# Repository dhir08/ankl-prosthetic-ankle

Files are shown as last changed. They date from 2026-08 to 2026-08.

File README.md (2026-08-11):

# ANKL — 3-DOF Pediatric Prosthetic Ankle

A three-degree-of-freedom prosthetic ankle designed to emulate natural gait motion for a pediatric patient, developed across five 3D-printed design iterations with linear actuators, custom joints, and a purpose-built PCB.

**Stack:** SolidWorks (parts, assemblies, drawings) · FEA · 3D printing (PLA) · linear actuators · custom PCB · electrical schematics · kinematic modeling
**Context:** Biomedical Engineering Project, Texas A&M University — January 2026 – present
**Role:** Mechanical design, electrical schematic design, PCB layout, iteration testing

---

## The problem

Commercial prosthetic ankles are overwhelmingly designed for adult anatomy and adult gait. Pediatric patients get scaled-down adult hardware, which means the wrong mass distribution on a body that has less strength to carry it, and joint kinematics that don't match a growing gait pattern. Weight is the binding constraint: every gram at the distal end of the limb costs disproportionate metabolic energy during swing phase.

## What was built

A 3-DOF ankle assembly — dorsiflexion/plantarflexion, inversion/eversion, and internal/external rotation — driven by linear actuators through custom-designed joints, with a kinematic model used to size actuator stroke and mounting geometry against target range of motion before anything was printed.

### Headline result

**Device weight reduced 1.6×** by designing the electrical schematics and a custom PCB from scratch, replacing discrete wiring and off-the-shelf boards, then repackaging the mechanical envelope around the smaller board footprint. The electrical redesign didn't just save board mass — it collapsed the wiring harness volume, which let the housing shrink.

## Design process

Five full iterations, each following the same loop:

1. **Model** — full parts and assemblies in SolidWorks, driven by the kinematic model for joint placement and actuator stroke
2. **Print** — 3D-printed prototype build
3. **Validate** — fit and range-of-motion checks on the physical build
4. **Feed back** — dimensional changes carried into the CAD model before the next print cycle

That last step is the one that matters. Each print exposed tolerance stack-up and interference that the model didn't predict, and the CAD was corrected rather than the print being shimmed.

| Iteration | Focus |
| --- | --- |
| 1 | Baseline 3-DOF joint architecture, actuator mounting feasibility |
| 2 | Joint geometry refinement against measured range of motion |
| 3 | Tolerance and clearance correction from physical fit testing |
| 4 | Electrical integration — schematic design and custom PCB |
| 5 | Mechanical envelope repackaged around the new board; weight reduction realized |

## Electrical design

Schematics and custom PCB components were designed from scratch rather than assembled from breakout boards. The goals, in order: cut mass, cut wiring complexity, and shrink the volume the electronics demand from the mechanical housing.

## Repository contents

```
cad/
  parts/            SolidWorks part files (.SLDPRT)
  assemblies/       Full ankle assemblies (.SLDASM)
  drawings/         Technical drawings (.SLDDRW, PDF exports)
  step/             Neutral-format STEP exports
electrical/
  schematics/       Electrical schematics
  pcb/              PCB layout files and Gerbers
  bom.csv           Bill of materials
analysis/
  kinematics/       Kinematic model and range-of-motion calculations
  fea/              FEA setup and results
docs/
  iteration-log.md  Per-iteration changes, measurements, and rationale
  images/           Renders and build photos
```

## Next steps

- Gait-cycle load testing beyond static fit and range-of-motion validation
- Actuator control tuning against measured pediatric gait profiles
- Material study — evaluating printed PLA against carbon-filled alternatives for the load-bearing members

## A note on files

CAD binaries are versioned here for completeness, but Git handles them as opaque blobs — diffs aren't meaningful. STEP exports are included so the geometry is reviewable without a SolidWorks license.

## License

MIT — see [LICENSE](LICENSE).

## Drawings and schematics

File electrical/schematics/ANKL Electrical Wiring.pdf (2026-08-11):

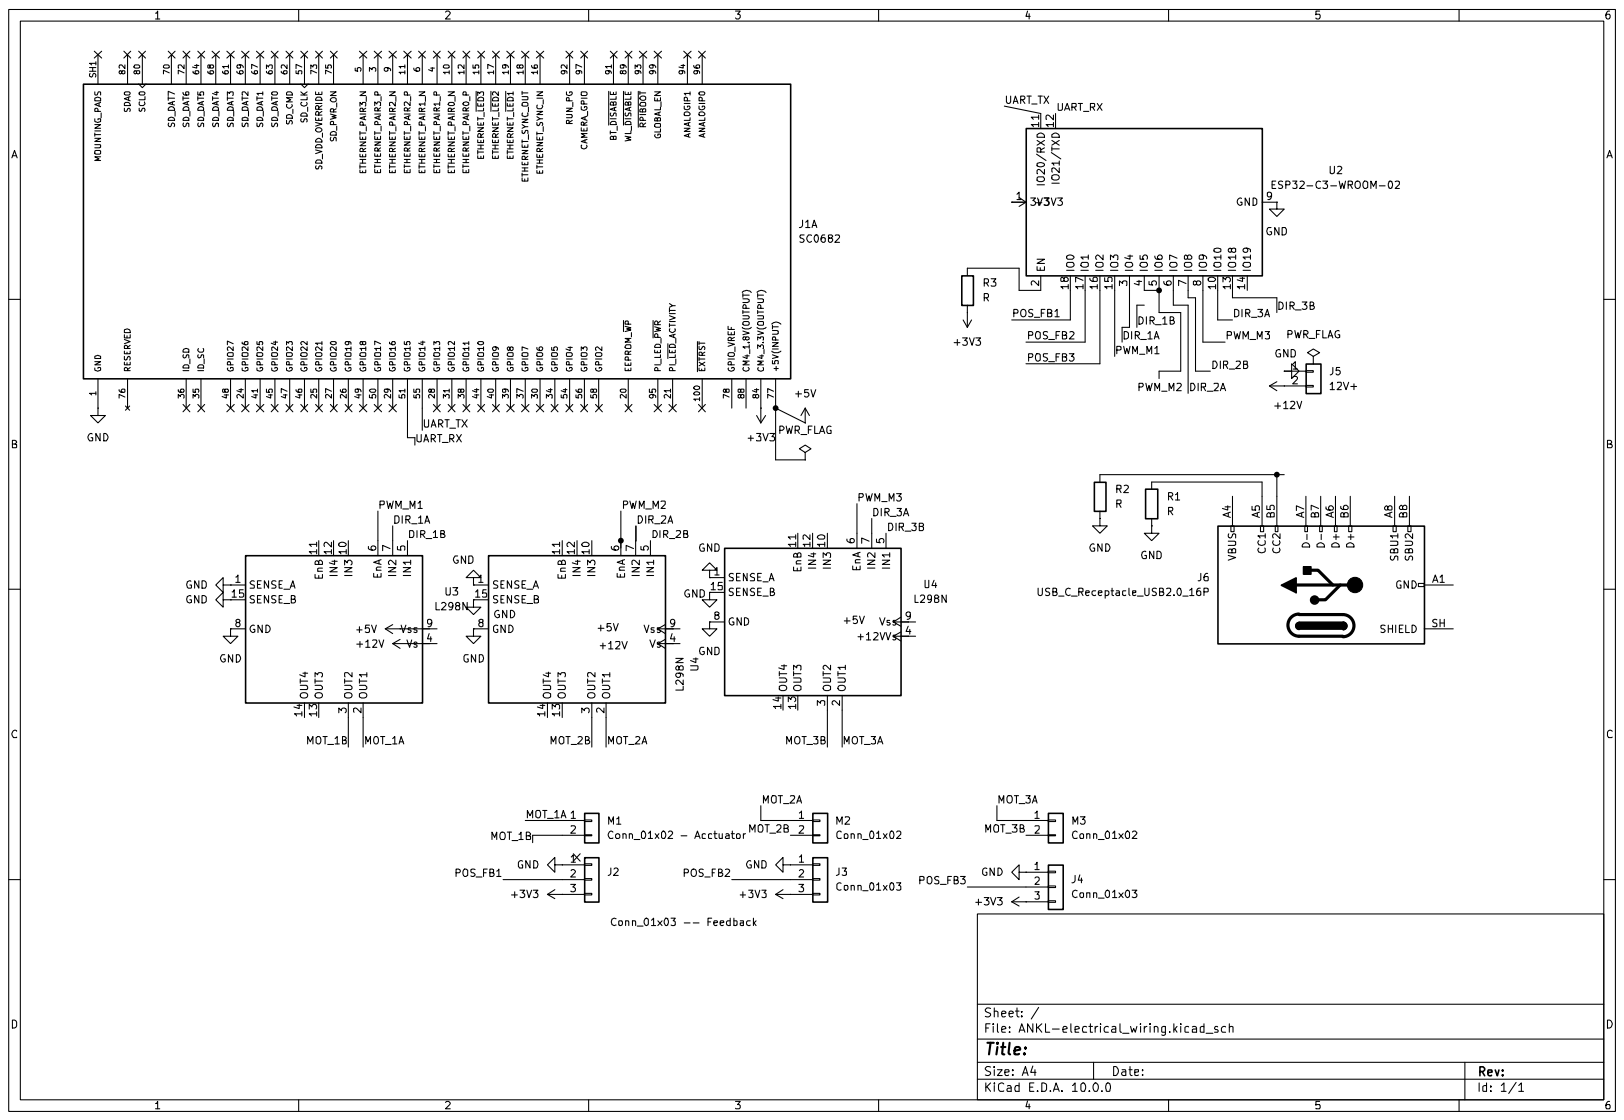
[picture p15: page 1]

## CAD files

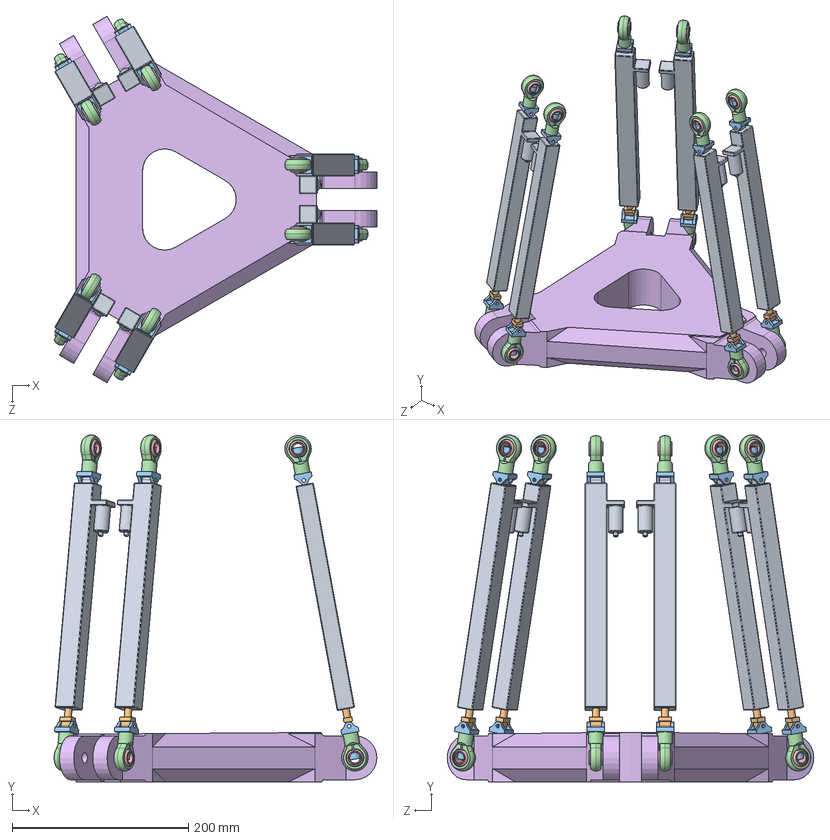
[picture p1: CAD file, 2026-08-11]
cad/assemblies/Assem1.SLDASM
366.6 x 394.1 x 416.3 mm
prototype base
rod ball x 12
Rod end x 12
actuator connector x 12
rough actuator rod x 6
actuator box x 6

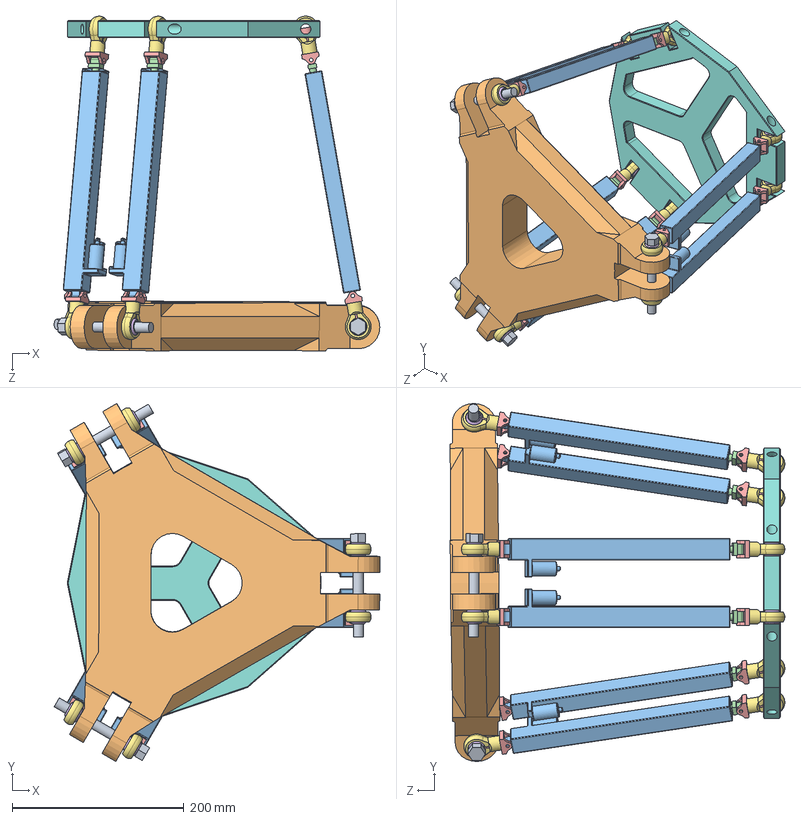
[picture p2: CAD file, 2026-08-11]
cad/assemblies/Base Prototype TURTLE_Full_cad.SLDASM
378.8 x 416.3 x 389.2 mm
Rod end x 12
rod ball x 12
actuator connector x 12
rough actuator rod x 6
actuator box x 6
prototype base
prototype polt x 3

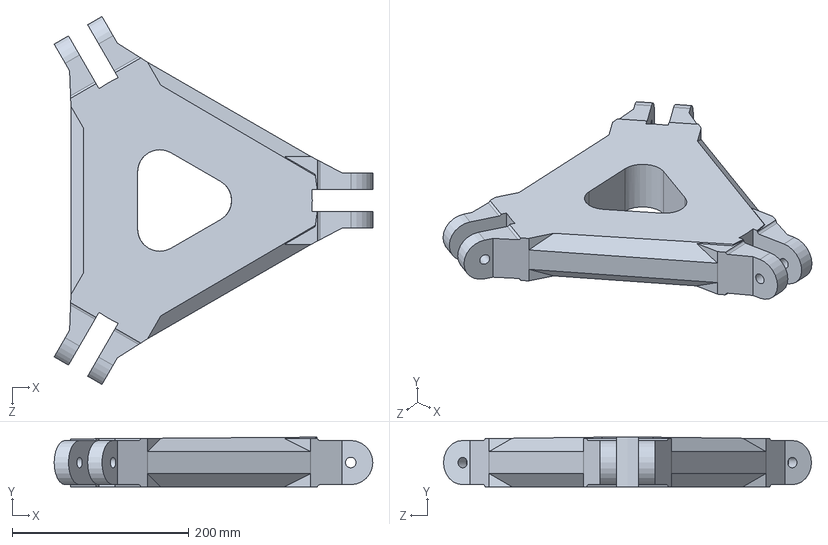
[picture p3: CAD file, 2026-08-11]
cad/parts/prototype base.SLDPRT
360.5 x 56.3 x 416.3 mm

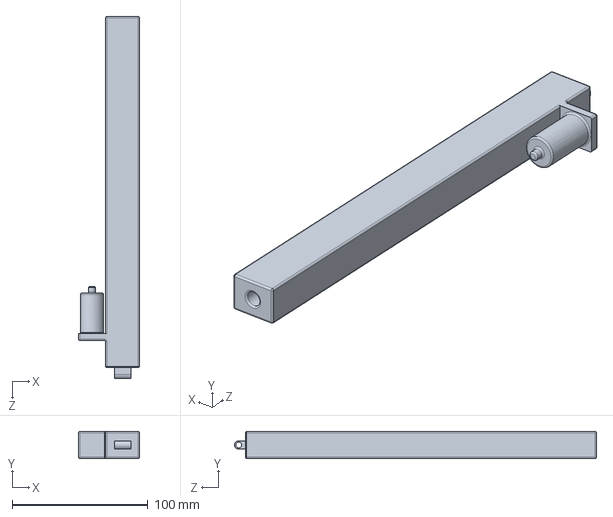
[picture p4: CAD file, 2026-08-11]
cad/parts/actuator box.SLDPRT
45.0 x 20.0 x 267.0 mm

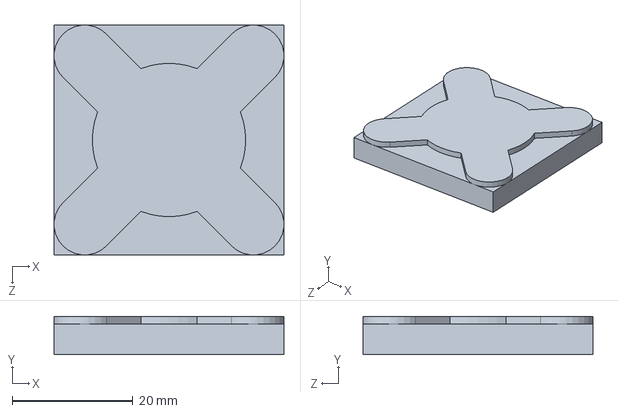
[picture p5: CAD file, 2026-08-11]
cad/parts/Square Flange.SLDPRT
38.1 x 6.35 x 38.1 mm

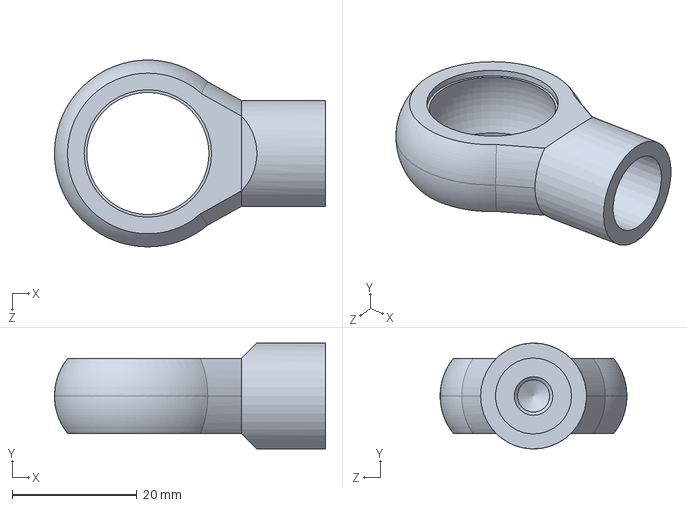
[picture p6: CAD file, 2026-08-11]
cad/parts/Rod end.SLDPRT
43.5 x 17.0 x 30.0 mm

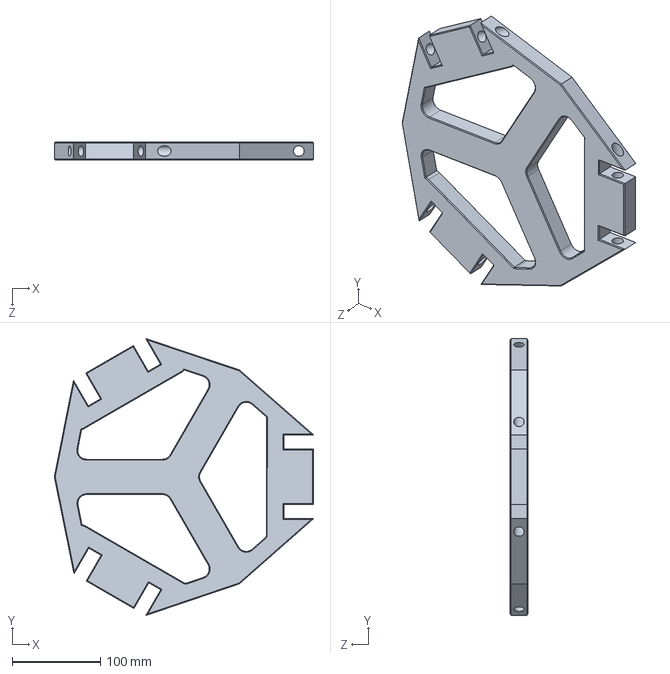
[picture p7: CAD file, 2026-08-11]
cad/parts/Part1.SLDPRT
294.1 x 314.1 x 20.0 mm

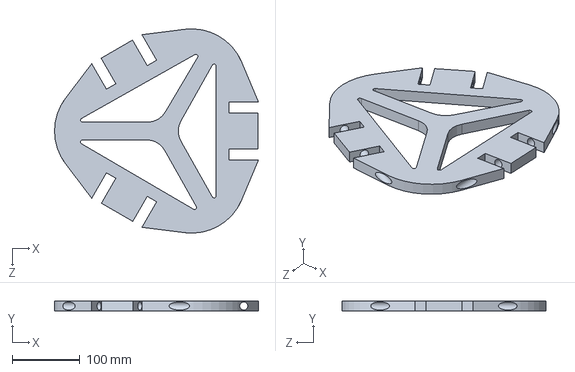
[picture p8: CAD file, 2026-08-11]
cad/parts/top of ankll.SLDPRT
300.9 x 15.0 x 301.2 mm

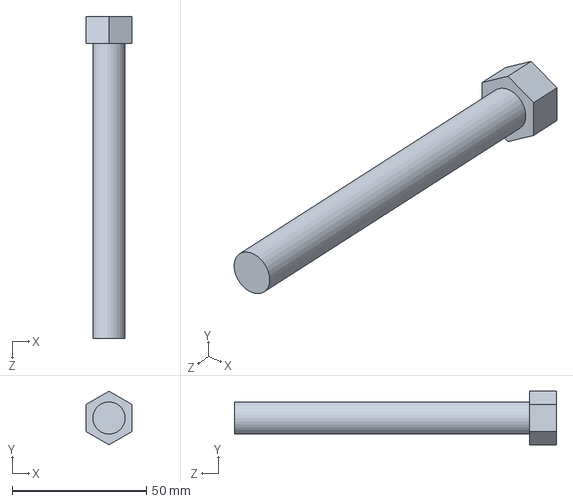
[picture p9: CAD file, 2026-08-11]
cad/parts/prototype polt.SLDPRT
17.3 x 20.0 x 120.0 mm

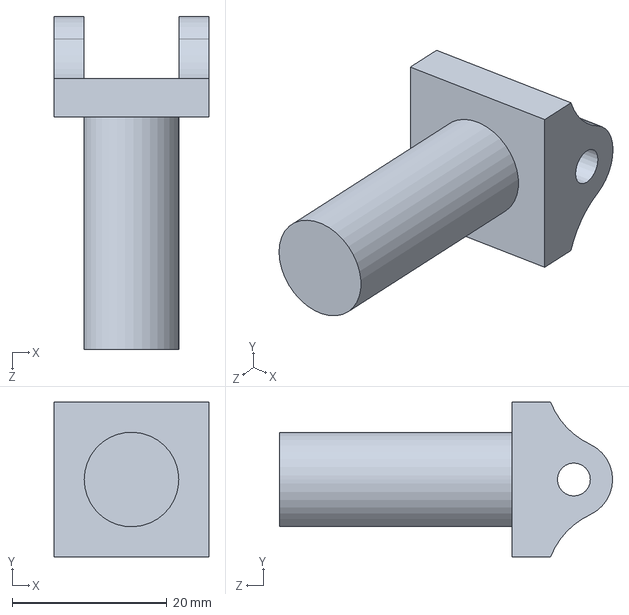
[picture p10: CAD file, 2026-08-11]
cad/parts/actuator connector.SLDPRT
20.0 x 20.0 x 43.0 mm

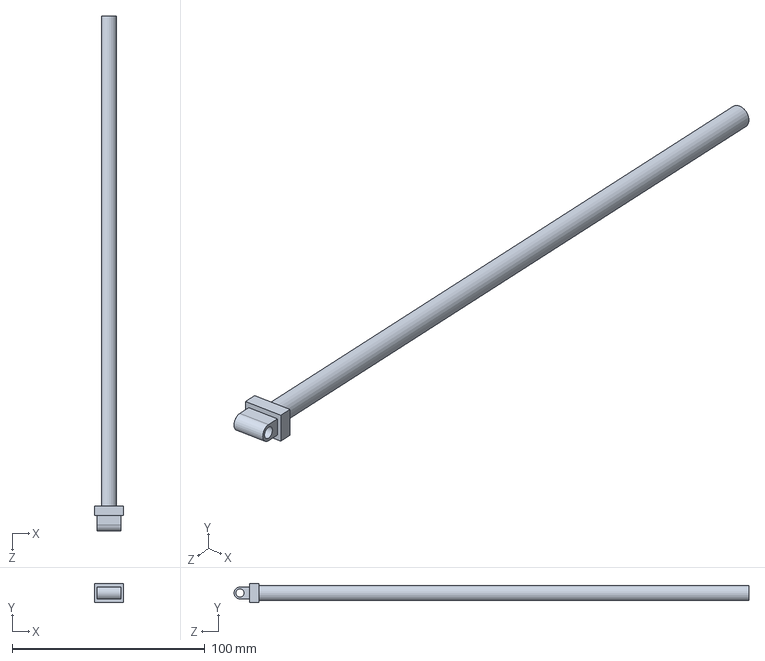
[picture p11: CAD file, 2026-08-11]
cad/parts/rough actuator rod.SLDPRT
15.0 x 10.0 x 267.0 mm

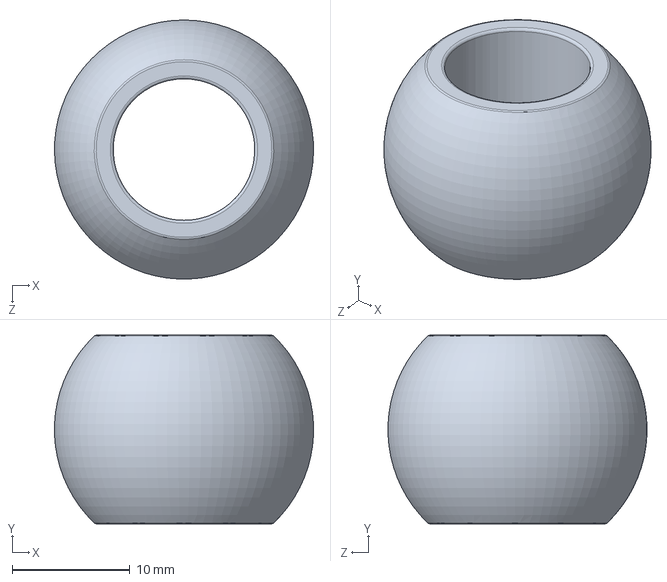
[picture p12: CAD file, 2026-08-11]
cad/parts/rod ball.SLDPRT
22.0 x 16.0 x 22.0 mm

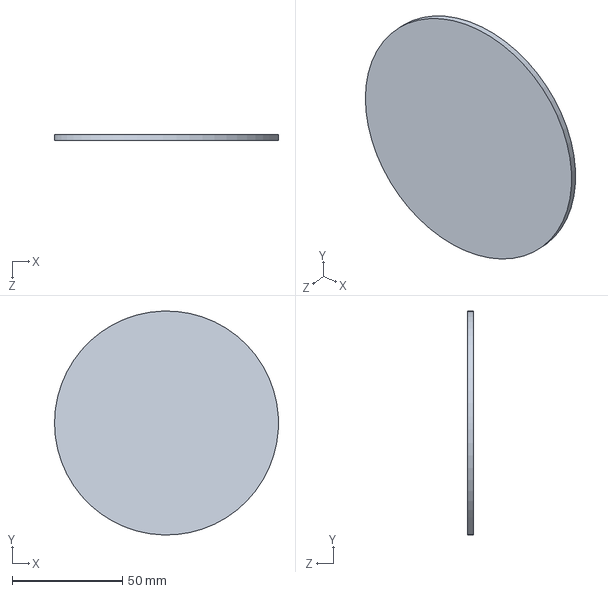
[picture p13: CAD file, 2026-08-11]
cad/parts/3x3 test.SLDPRT
101.6 x 101.6 x 2.54 mm

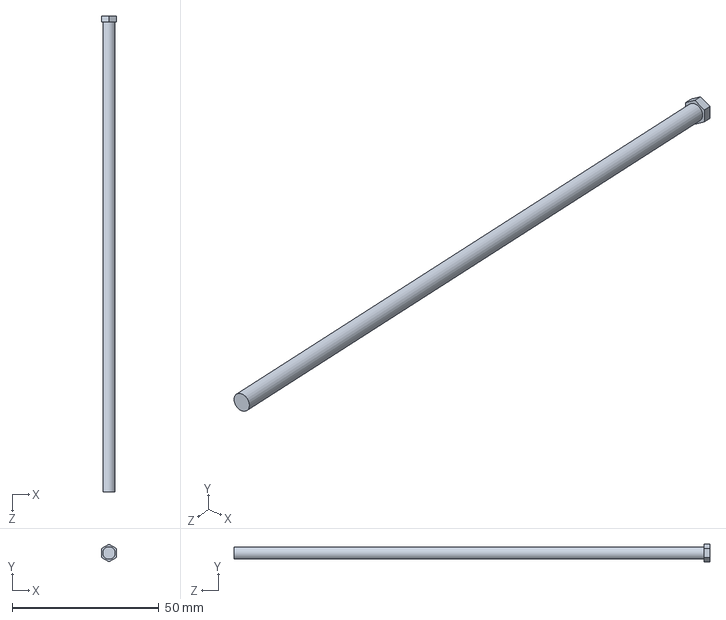
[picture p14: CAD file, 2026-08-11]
cad/parts/top bolt.SLDPRT
5.20 x 6.00 x 162.0 mm
